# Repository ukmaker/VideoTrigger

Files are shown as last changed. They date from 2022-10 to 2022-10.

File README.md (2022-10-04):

# VideoTrigger
My oscilloscope wouldn't trigger relibly on the video signal from my TMS9128 VDP, so I made this to help me work on my VDPtoTFT project. 

# Why?
Builders (and possessors) of retro-computers have many options for generating video. One of the chips used in computers in the early 80's was the TMS9918 family of Video Display Processors.

Because I had a semi-rational excuse for wanting to make my chip drive a small TFT display (the rabbit-hole starts [here](https://github.com/ukmaker/VDPtoTFT)), I needed to be able to view the video outputs on my oscilloscope. My 'scope has a "Video Trigger" mode, which I gleefully enabled in anticipation of a nice, rock-solid display. No dice. No triggering of any sort was happening. This turns out not to be (totally) the fault of my 'scope - a Hantek DSO1502P. I think this is because the output from the chip isn't really a conformant video signal. I'm not entirely sure why, unless the scope expects "normal" voltage levels which take quite some work to produce from what the chip outputs.

So, in order to view the signals properly, I needed an external trigger signal. Hence this project. It uses the well known LM1881 sync separator IC to derive horizontal and vertical sync from the chip's "Y" output. These in turn feed an Atemga328P - programmed using the Arduino framework - which allows user selection of 
  - which edge of hsync to trigger off
  - which line to trigger off
These are selectable by pushing and turning a rotary encoder, and the setting is display on a small OLED display.

The output from the LM1881 is used to clock a pair of JK flip-flops - one for the positive and one for the negative edge of the sync signal - and the negative-edge clock is inverted using a transistor. The appropriate flip-flop is enabled by the Atmega328 for the duration of the chosen line. The outputs are ORed together using diode logic and a resistor.

Here is the circuit built on a bit of protoboard. It is powered from the scope's USB port. Input signal is on the left, trigger output is on the right.
[The Video Trigger](./images/VideoTrigger.JPG)

This picture shows the video signal and the trigger signal. Note that the trigger output from my circuit is the falling edge of the blue signal - the rising edge occurs an arbitrary time after the horizontal trigger signal, and is a very slow edge.
[Triggering on the falling edge](./images/NegativeTrigger.png)

And in this image you can see the slow rising edge of the trigger signal
[Triggering on the rising edge](./images/PositiveTrigger.png)

# Is It Any Good?
Well, it's good enough for me :-)

The input buffer is tailored to the output of the VDP. If the signal you use as the input does not have a DC offset of 2V, you'll need to bias the transistor up and add an input decoupling capacitor.

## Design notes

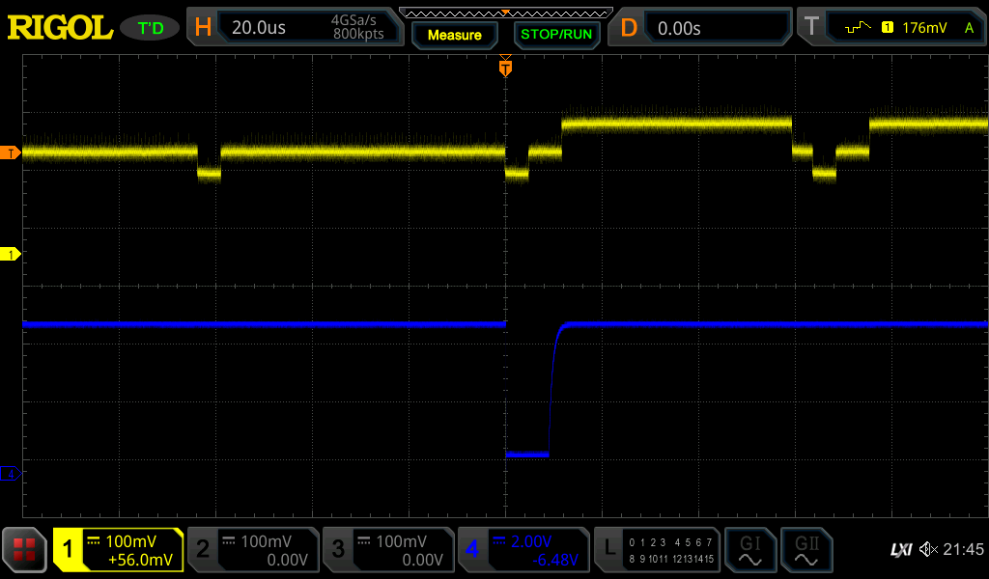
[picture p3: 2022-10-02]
images/NegativeTrigger.png

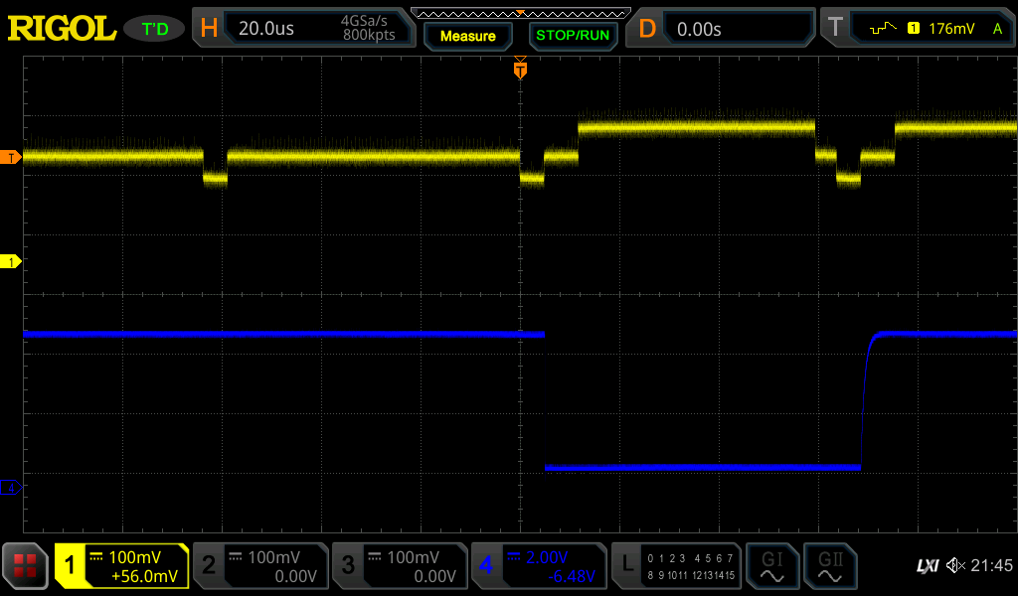
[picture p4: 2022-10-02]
images/PositiveTrigger.png

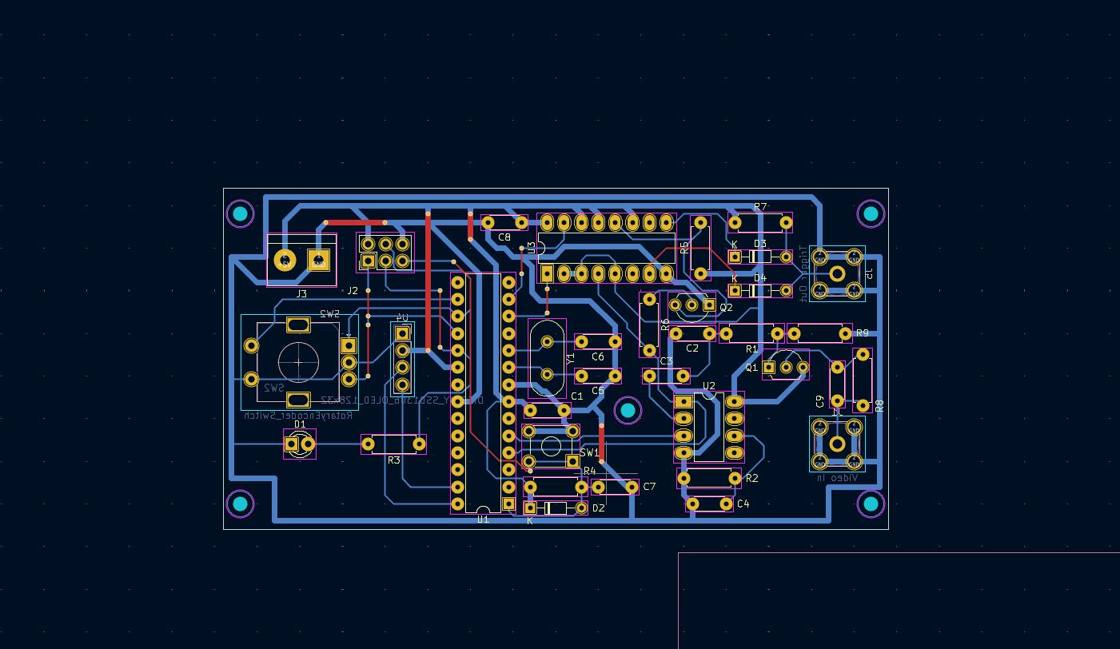
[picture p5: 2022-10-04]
KiCAD/VideoTrigger/VideoTriggerPCB3D.jpg

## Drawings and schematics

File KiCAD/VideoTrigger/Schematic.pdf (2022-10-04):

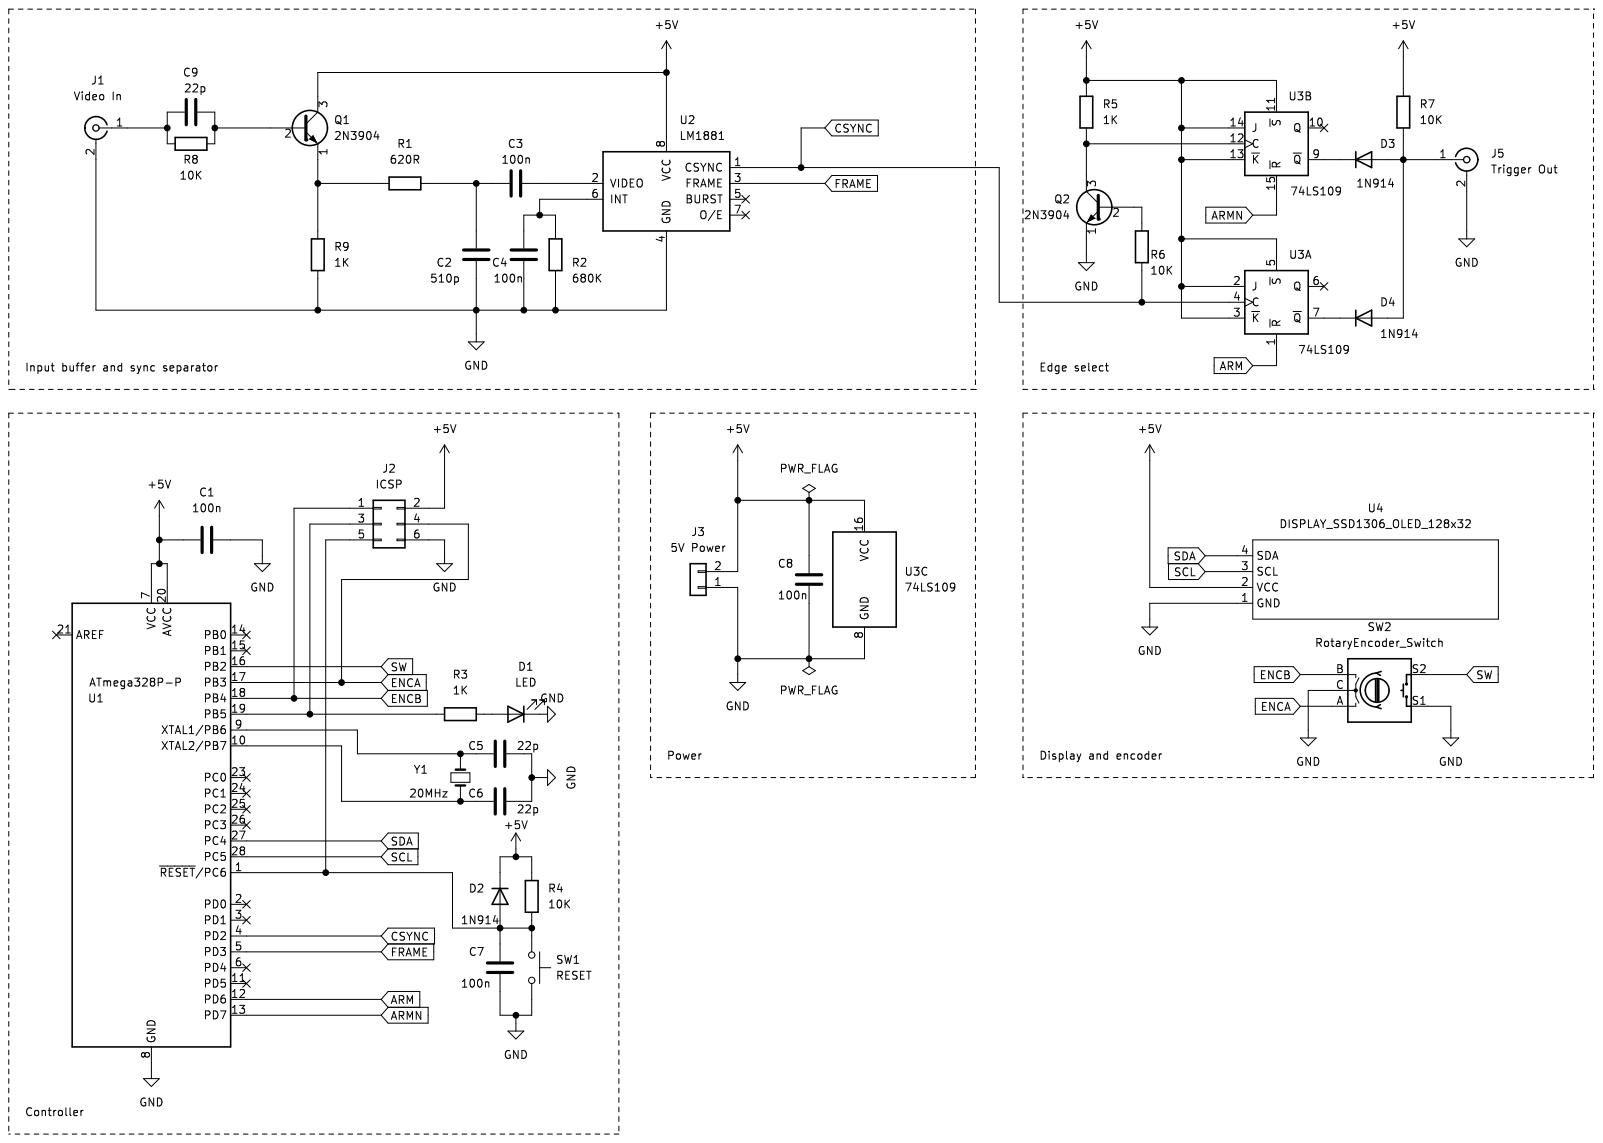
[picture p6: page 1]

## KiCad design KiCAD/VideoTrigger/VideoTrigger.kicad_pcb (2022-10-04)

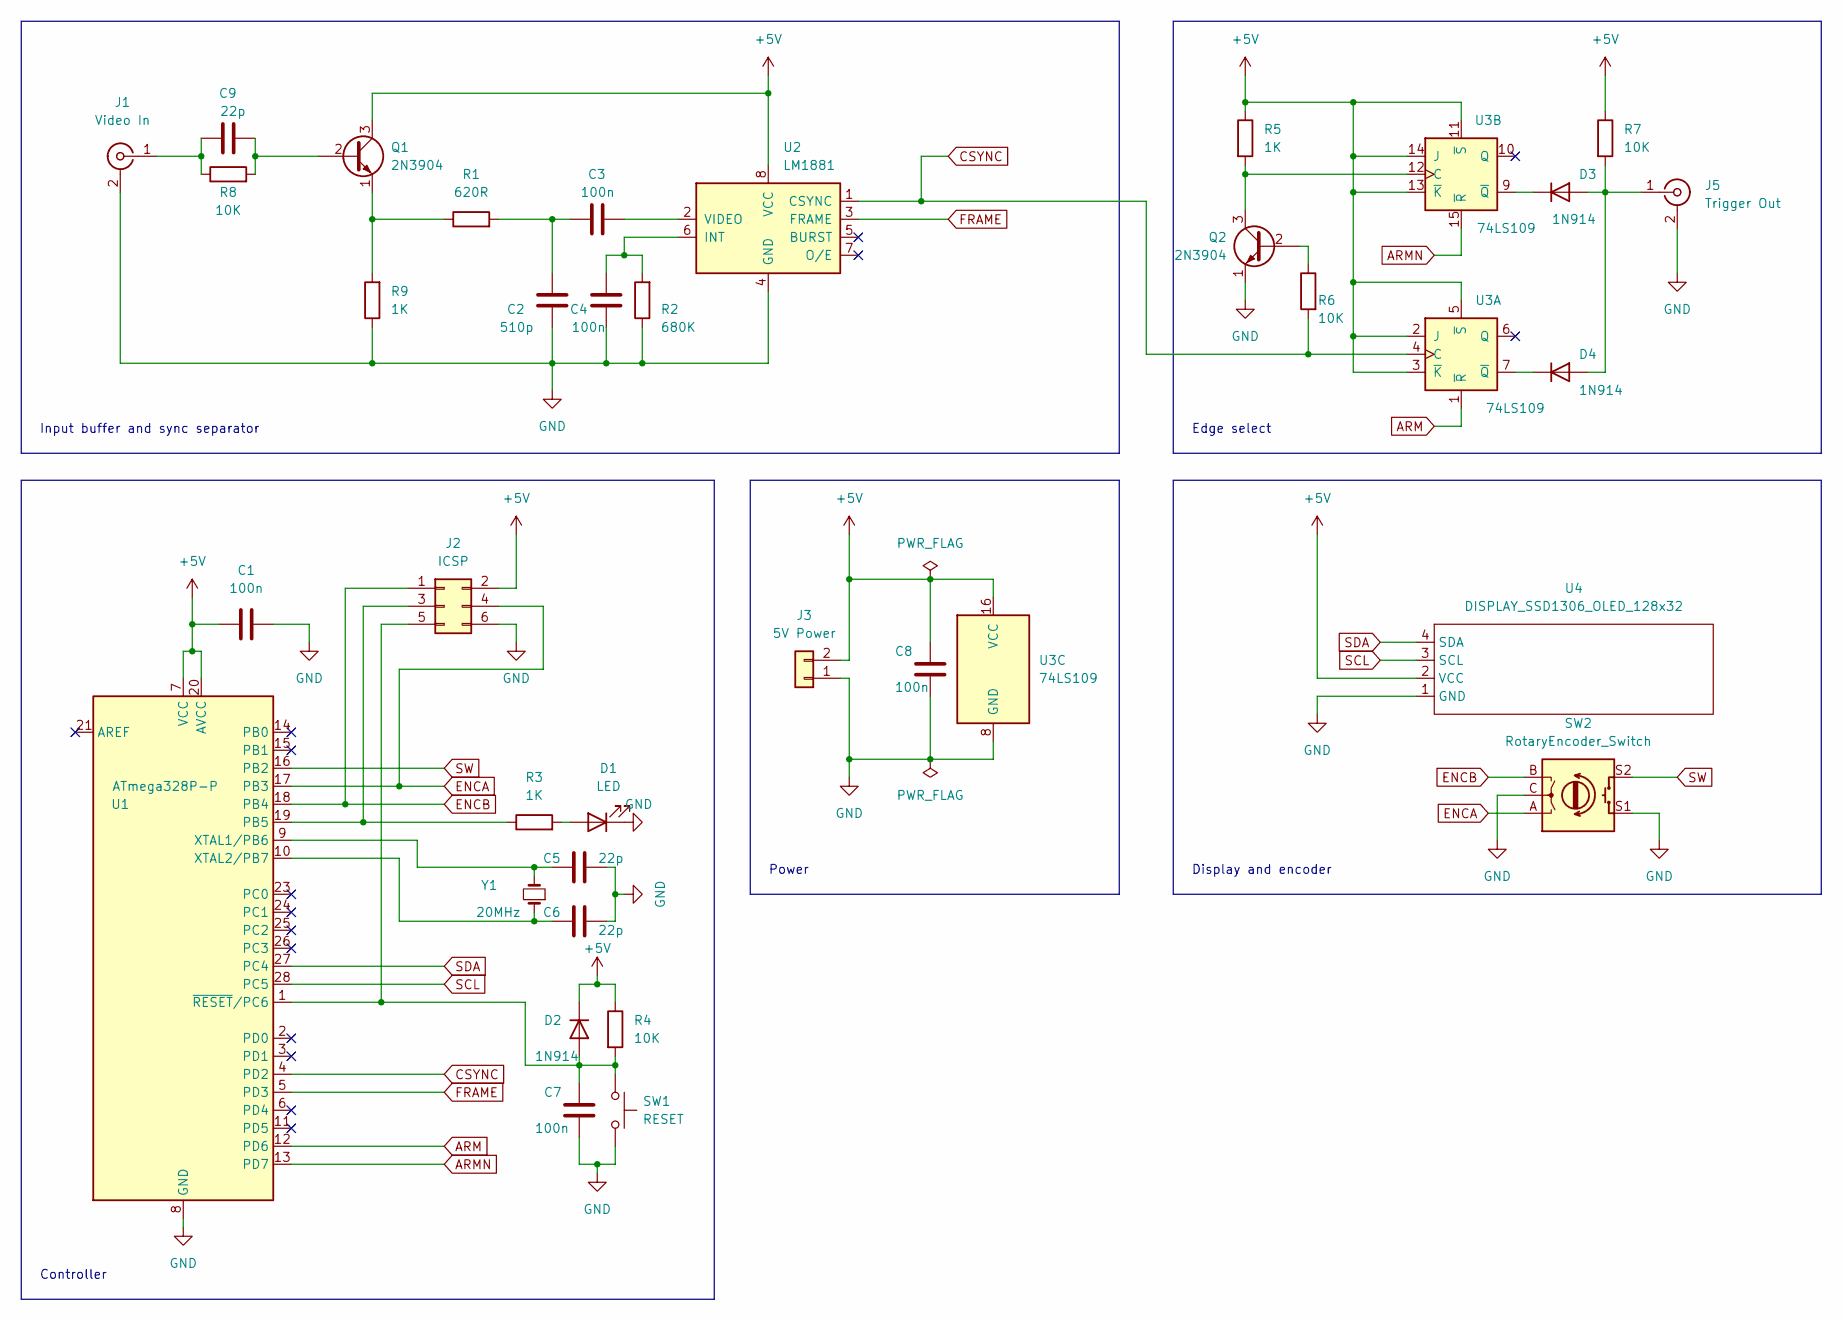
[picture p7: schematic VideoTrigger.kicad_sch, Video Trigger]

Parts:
C1, C3, C4, C7, C8: 100n; C_Disc_D4.3mm_W1.9mm_P5.00mm
C2: 510p; C_Disc_D4.3mm_W1.9mm_P5.00mm
C5, C6, C9: 22p; C_Disc_D4.3mm_W1.9mm_P5.00mm
D1: LED; LED_D3.0mm
D2, D3, D4: 1N914; D_DO-34_SOD68_P7.62mm_Horizontal
J1: Video In; SMA_Amphenol_901-144_Vertical
J2: ICSP; PinHeader_2x03_P2.54mm_Vertical
J3: 5V Power; TerminalBlock_bornier-2_P5.08mm
J5: Trigger Out; SMA_Amphenol_901-144_Vertical
Q1, Q2: 2N3904; TO-92L_Inline_Wide
R1: 620R; R_Axial_DIN0207_L6.3mm_D2.5mm_P7.62mm_Horizontal
R2: 680K; R_Axial_DIN0207_L6.3mm_D2.5mm_P7.62mm_Horizontal
R3, R5, R9: 1K; R_Axial_DIN0207_L6.3mm_D2.5mm_P7.62mm_Horizontal
R4, R6, R7, R8: 10K; R_Axial_DIN0207_L6.3mm_D2.5mm_P7.62mm_Horizontal
SW1: RESET; SW_TH_Tactile_Omron_B3F-10xx
SW2: RotaryEncoder_Switch; RotaryEncoder_Alps_EC11E-Switch_Vertical_H20mm
U1: ATmega328P-P; DIP-28_W7.62mm
U2: LM1881; DIP-8_W7.62mm_LongPads
U3: 74LS109; DIP-16_W7.62mm_LongPads
U4: DISPLAY_SSD1306_OLED_128x32; PinHeader_1x04_P2.54mm_Vertical
Y1: 20MHz; Crystal_HC49-U_Vertical

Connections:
+5V: C1.1, C8.1, D2.1 (K), J2.2, J3.2, Q1.3 (C), R4.1, R5.1, R7.1, U1.7 (VCC), U1.20 (AVCC), U2.8 (VCC), U3.2 (J), U3.3 (~K), U3.5 (~S), U3.11 (~S), U3.13 (~K), U3.14 (J), U3.16 (VCC), U4.2 (VCC)
ARM: U1.12 (PD6), U3.1 (~R)
ARMN: U1.13 (PD7), U3.15 (~R)
CSYNC: R6.2, U1.4 (PD2), U2.1 (CSYNC), U3.4 (C)
ENCA: J2.4, SW2.A, U1.17 (PB3)
ENCB: J2.1, SW2.B, U1.18 (PB4)
FRAME: U1.5 (PD3), U2.3 (FRAME)
GND: C1.2, C2.2, C4.2, C5.1, C6.1, C7.2, C8.2, D1.1 (K), J1.2 (Ext), J2.6, J3.1, J5.2 (Ext), Q2.1 (E), R2.1, R9.1, SW1.2, SW2.C, SW2.S1, U1.8 (GND), U1.22 (GND), U2.4 (GND), U3.8 (GND), U4.1 (GND)
unnamed: C2.1, C3.2, R1.2
unnamed: C3.1, U2.2 (VIDEO)
unnamed: C4.1, R2.2, U2.6 (INT)
unnamed: C5.2, U1.9 (XTAL1/PB6), Y1.2
unnamed: C6.2, U1.10 (XTAL2/PB7), Y1.1
unnamed: C7.1, D2.2 (A), J2.5, R4.2, SW1.1, U1.1 (~RESET/PC6)
unnamed: C9.1, Q1.2 (B), R8.2
unnamed: C9.2, J1.1 (In), R8.1
unnamed: D3.1 (K), U3.9 (~Q)
unnamed: D3.2 (A), D4.2 (A), J5.1 (In), R7.2
unnamed: D4.1 (K), U3.7 (~Q)
unnamed: J2.3, R3.1, U1.19 (PB5)
unnamed: Q1.1 (E), R1.1, R9.2
unnamed: D1.2 (A), R3.2
unnamed: Q2.3 (C), R5.2, U3.12 (C)
unnamed: Q2.2 (B), R6.1
SCL: U1.28 (PC5), U4.3 (SCL)
SDA: U1.27 (PC4), U4.4 (SDA)
SW: SW2.S2, U1.16 (PB2)

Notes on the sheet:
Controller
Display and encoder
Power
Edge select
Input buffer and sync separator

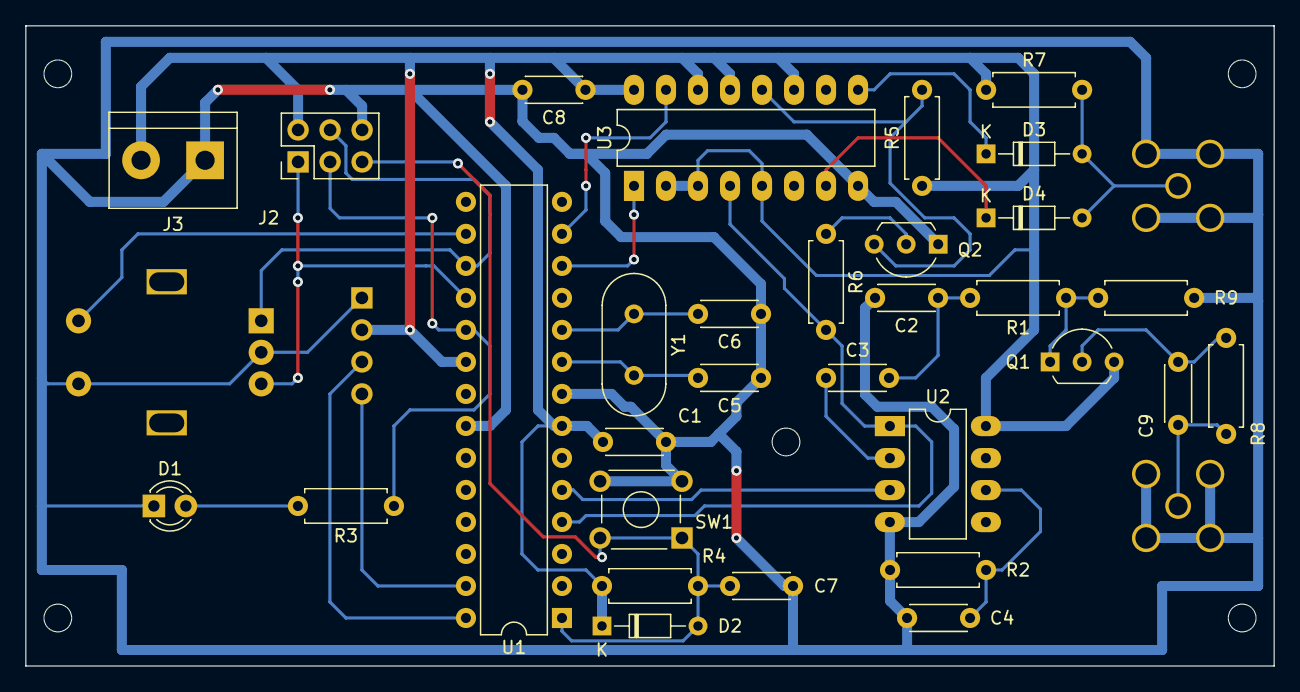
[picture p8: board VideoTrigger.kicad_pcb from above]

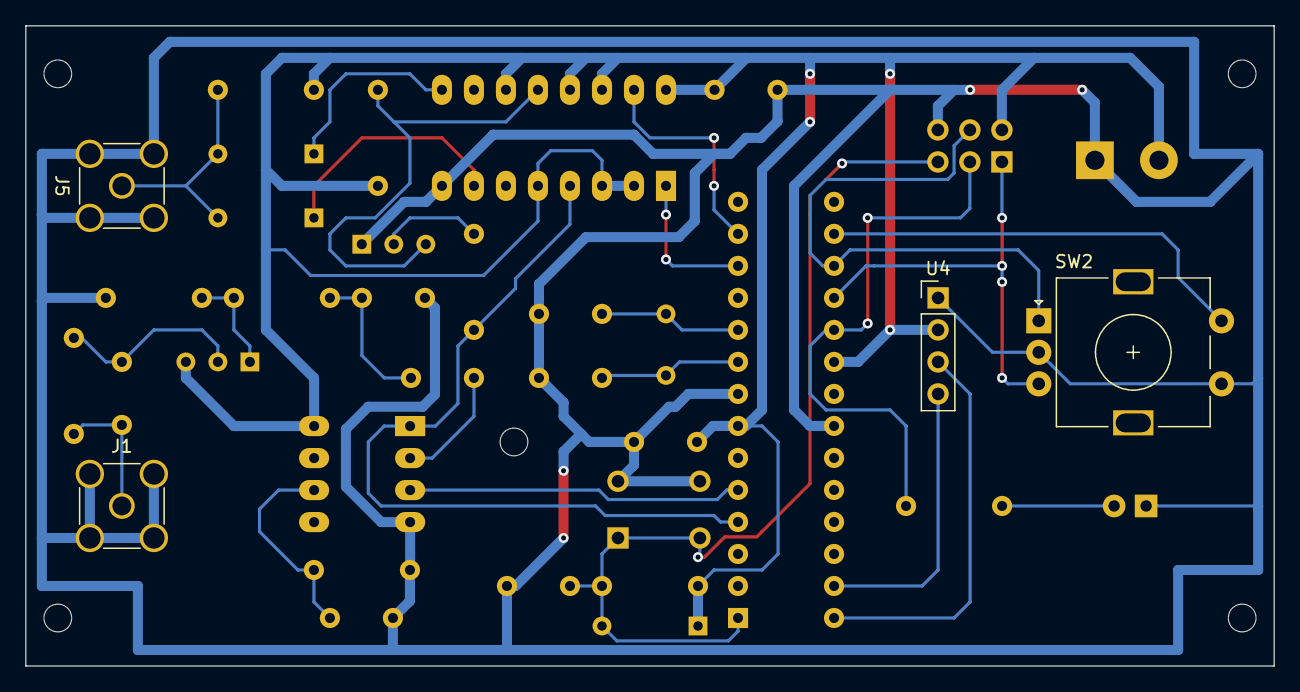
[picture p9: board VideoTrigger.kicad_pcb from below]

Board: 2 copper layers, 99.1 x 50.8 mm, 35 parts (4 on the bottom side), 27 nets.

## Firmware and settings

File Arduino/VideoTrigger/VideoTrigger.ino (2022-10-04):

#include <EncoderButton.h>
#include <SPI.h>
#include <Wire.h>
#include <Adafruit_GFX.h>
#include <Adafruit_SSD1306.h>


#define INTER_FRAME_LINES 11

// Actually 312.5
#define PAL_LINES 313
#define PAL_VISIBLE_LINES 288

// Actually 262.5
#define NTSC_LINES 263
#define NTSC_VISIBLE_LINES 238
#define ARM 7
#define ARMN 6
#define ENCA 11
#define ENCB 12
#define ENCC 10
#define ARMND (1<<7)
#define ARMD (1<<6)

#define SCREEN_WIDTH 128 // OLED display width, in pixels
#define SCREEN_HEIGHT 32 // OLED display height, in pixels
#define OLED_RESET     -1 // Reset pin # (or -1 if sharing Arduino reset pin)
#define SCREEN_ADDRESS 0x3C ///< See datasheet for Address; 0x3D for 128x64, 0x3C for 128x32
Adafruit_SSD1306 display(SCREEN_WIDTH, SCREEN_HEIGHT, &Wire, OLED_RESET);


volatile int line = 0;
volatile int lines = 0;
volatile int trigger = 24;
volatile int maxlines = 0;
volatile bool falling = false;
volatile bool armed = false;
volatile uint8_t arm = ARMD;
volatile uint8_t frames = 0;
int lastTrigger = 0;
int lastPolarity = false;


EncoderButton eb1(ENCA, ENCB, ENCC);

void onEb1Clicked(EncoderButton& eb) {
  falling = !falling;
  detachInterrupt(digitalPinToInterrupt(2));
  if (falling) {
    attachInterrupt(digitalPinToInterrupt(2), hsync, FALLING);
    arm = ARMD;
  } else {
    attachInterrupt(digitalPinToInterrupt(2), hsync, RISING);
    arm = ARMND;
  }
  maxlines = 0;
}

void onEb1Encoder(EncoderButton& eb) {
  long pos = eb.position();
  if (pos > maxlines) pos = 1;
  if (pos <= 0) pos = maxlines;
  trigger = pos;
}

void onButton1LongPress(EncoderButton& eb) {
  trigger = 1;
}

void setup() {

  pinMode(ARM, OUTPUT);
  pinMode(ARMN, OUTPUT);
  digitalWrite(ARM, HIGH);
  digitalWrite(ARMN, LOW);
  // setup the encoder and screen

  //Link the event(s) to your function
  eb1.setClickHandler(onEb1Clicked);
  eb1.setEncoderHandler(onEb1Encoder);
  eb1.setLongPressHandler(onButton1LongPress, false);

  display.begin(SSD1306_SWITCHCAPVCC, SCREEN_ADDRESS);
  display.display();
  display.clearDisplay();

  display.setTextSize(2); // Draw 2X-scale text
  display.setTextColor(SSD1306_WHITE);
  display.setCursor(0, 0);
  display.println(("Video"));
  display.println(("Trigger"));
  display.display();
  delay(1000);
  display.setCursor(10, 0);
  eb1.resetPosition(trigger);
  attachInterrupt(digitalPinToInterrupt(3), vsync, FALLING);
  attachInterrupt(digitalPinToInterrupt(2), hsync, FALLING);
}

void loop() {
  // put your main code here, to run repeatedly:
  // reset the line count every now and then in case we got a glitch
  if(frames == 0) {
    maxlines = 0;
  }
  eb1.update();
  if (lastTrigger != trigger || lastPolarity != falling) {
    lastTrigger = trigger;
    lastPolarity = falling;

    eb1.resetPosition(trigger);

    display.clearDisplay();
    display.setCursor(0, 0);

    if (!falling) {
      display.print("\\_");
    } else {
      display.print("_/");
    }
    display.print(trigger, DEC);
    display.print("/");
    display.print(maxlines);
    display.display();
  }
}


void hsync() {

  if (line == trigger) {
    PORTD |= arm;
  } else {
    PORTD &= 0x3f;
  }

  lines++;
  line++;
  if (line > maxlines) line = 1;
}

void vsync() {
  line = maxlines - INTER_FRAME_LINES;
  if (lines > maxlines) maxlines = lines;
  lines = 0;
  frames++;
}

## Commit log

2022-09-11 Initial import
    [VideoTrigger.kicad_pcb, VideoTrigger.kicad_sch]
2022-10-02 Updated README and schematic
    [VideoTrigger.kicad_sch]
2022-10-04 Added input buffering, updated README
    [VideoTrigger.kicad_sch]
2022-10-04 Added PCB layout. Some signal changes to make routing easier
    [VideoTrigger-B_Cu.gbr, VideoTrigger-B_Mask.gbr, VideoTrigger-B_Paste.gbr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]
